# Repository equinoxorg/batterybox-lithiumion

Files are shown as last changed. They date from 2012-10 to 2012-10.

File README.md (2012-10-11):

# 3.7V Lithium Ion Battery Box Prototype

Electrial Engineering Final Year Project Deliverable
Charith Amarasinghe <ca508@ic.ac.uk>

3.7V Li-Ion Battery Box Prototype

## Features

* 1SxP Lithium Ion Battery Configuration (~1A nominal charge current)
* Li-Ion Fuel Gauge
* 2x 5V/1A USB outputs with short-circuit and overcurrent protection
* Authenticated charge support via MicroUSB
* Charge support from DC input (compatible with small PV panels)
* Constant Current LED driver (1-2W dimmable)
* Additional UART support (via Molex PicoBlade connectors) for datalogging applications
* 2x User Control Buttons
* LED indicators for low battery, USB fault and charge status

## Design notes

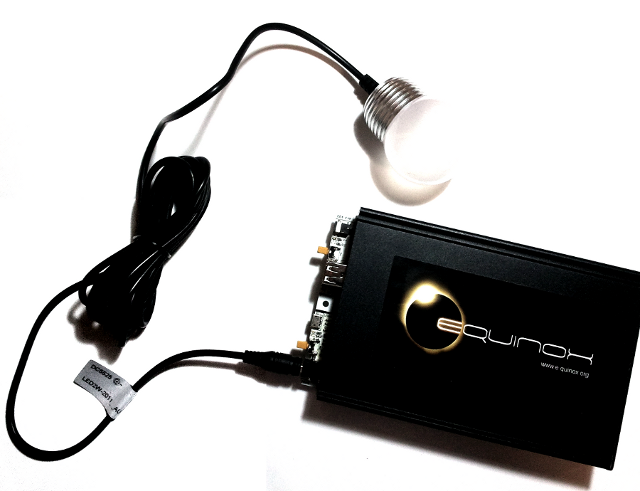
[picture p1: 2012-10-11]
media/proto.png

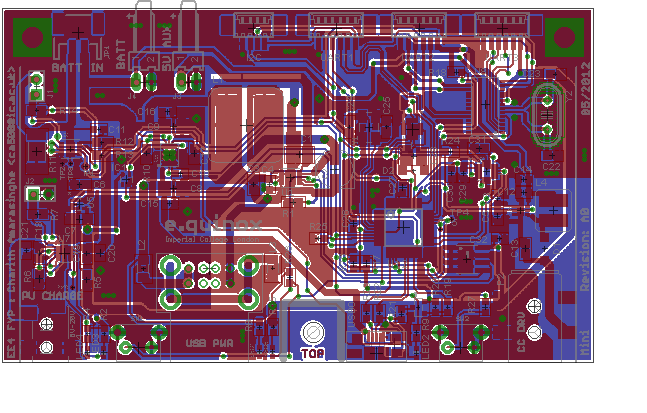
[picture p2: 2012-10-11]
media/pcb.png

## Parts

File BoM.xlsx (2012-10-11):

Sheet: Sheet1
Part | Value | Device | Package | Description | FARNELL | OC_FARNELL
!RESET! | TPSTP13SQ | TPSTP13SQ | TP13SQ | TEST PIN
1V8 | TPSTP13SQ | TPSTP13SQ | TP13SQ | TEST PIN
C1 | 22uF | C-EUC1210 | C1210 | CAPACITOR, European symbol | 1907362
C2 | 150uF | CPOL-EUD | PANASONIC_D | POLARIZED CAPACITOR, European symbol | 1850096
C3 | 10uF | C-EUC0805 | C0805 | CAPACITOR, European symbol | 1833812
C4 | 0.1uF | C-EUC0603 | C0603 | CAPACITOR, European symbol
C5 | 220nF | C-EUC0603 | C0603 | CAPACITOR, European symbol
C6 | 100nF | C-EUC0805 | C0805 | CAPACITOR, European symbol
C7 | 1uF | C-EUC1206 | C1206 | CAPACITOR, European symbol
C8 | 10uF | CPOL-EUB/3528-21R | B/3528-21R | POLARIZED CAPACITOR, European symbol | CA06845
C9 | 10uF | CPOL-EUB/3528-21R | B/3528-21R | POLARIZED CAPACITOR, European symbol | CA06845
C10 | 1n | C-EUC0603 | C0603 | CAPACITOR, European symbol
C11 | 10n | C-EUC0603 | C0603 | CAPACITOR, European symbol
C12 | 1uF | C-EUC0603 | C0603 | CAPACITOR, European symbol | 1828798
C13 | 1uF | C-EUC0805 | C0805 | CAPACITOR, European symbol | 1735541
C14 | 0.1uF | C-EUC0603 | C0603 | CAPACITOR, European symbol
C15 | 100n | C-EUC0603 | C0603 | CAPACITOR, European symbol
C16 | 100n | C-EUC0603 | C0603 | CAPACITOR, European symbol
C17 | 1uF | C-EUC0805 | C0805 | CAPACITOR, European symbol
C18 | 1uF | C-EUC0805 | C0805 | CAPACITOR, European symbol | 1735541
C19 | 1uF | C-EUC0805 | C0805 | CAPACITOR, European symbol | 1833845
C20 | 100n | C-EUC0603 | C0603 | CAPACITOR, European symbol
C21 | 100n | C-EUC0603 | C0603 | CAPACITOR, European symbol
C22 |  | C-EUC0805 | C0805 | CAPACITOR, European symbol
C23 |  | C-EUC0805 | C0805 | CAPACITOR, European symbol
C24 |  | C-EUC0805 | C0805 | CAPACITOR, European symbol
C25 |  | C-EUC0805 | C0805 | CAPACITOR, European symbol
C26 | 100n | C-EUC0603 | C0603 | CAPACITOR, European symbol
C27 | 100n | C-EUC0603 | C0603 | CAPACITOR, European symbol
C28 | 0.015F | C-EUC3225 | C3225 | CAPACITOR, European symbol
C29 | 0.1uF | C-EUC0603 | C0603 | CAPACITOR, European symbol
C30 | 0.1uF | C-EUC0603 | C0603 | CAPACITOR, European symbol
C31 | 4.7uF | C-EUC0805 | C0805 | CAPACITOR, European symbol
C32 | 0.1uF | C-EUC0603 | C0603 | CAPACITOR, European symbol
D1 | MBR0540T1 | MBR0520LT | SOD123 | SCHOTTKY BARRIER RECTIFIER | 9556923
D2 |  | DIODE-SOD123 | SOD123 | DIODE
GND | TPSTP13SQ | TPSTP13SQ | TP13SQ | TEST PIN
I2C | 53261-04 | 53261-04 | 53261-04 | CONNECTOR |  | 1125374
IC1 | 74LVC1G06DCK | 74LVC1G06DCK | SC70-5 | Single Inverter Buffer/Driver With Open-Drain Output
J1 | F-1X02-SIP-100-40 | F-1X02-SIP-100-40 | SIP-100-02-40 | FEMALE HEADER
J2 | F-1X02-SIP-100-40 | F-1X02-SIP-100-40 | SIP-100-02-40 | FEMALE HEADER
J3 | 22-05-7028-02 | 22-05-7028-02 | 7395-02 | CONNECTOR |  | 9731601
J4 | 22-05-7028-02 | 22-05-7028-02 | 7395-02 | CONNECTOR |  | 9731601
JP1 |  | M02-JST-2MM-SMT | JST-2-SMD | Header 2
L1 | 2.2uH | SDR1006-XXXKL | SDR1006 |  | 1828074
L2 | 30ohm | L-EUL3216C | L3216C | INDUCTOR, European symbol | FT01179
L3 | 30ohm | L-EUL3216C | L3216C | INDUCTOR, European symbol | FT01179
L4 | 22uH | VLCF5020-1 | VLCF-SERIES |  | 1670099
LED1 | USB_ON | LEDCHIP-LED0603 | CHIP-LED0603 | LED
LED2 | USB_CHG_GD | LEDCHIP-LED0603 | CHIP-LED0603 | LED
LED3 | CHG | LEDCHIP-LED0603 | CHIP-LED0603 | LED
LED4 | PG | LEDCHIP-LED0603 | CHIP-LED0603 | LED
LED5 | USB_FAULT | LEDCHIP-LED0603 | CHIP-LED0603 | LED
LED6 | USRLED | LEDCHIP-LED0603 | CHIP-LED0603 | LED
P1 | CLIFF_DCJACK1.3MM | CLIFF_DCJACK1.3MM | FC68145S
P2 | CLIFF_DCJACK2.1-2.5MM | CLIFF_DCJACK2.1-2.5MM | FC6814XS
Q1 | MMBT2907 | TRANSISTOR_PNPSOT23-REFLOW | SOT23-R | PNP Transistor
R1 | 28.7k | R-EU_R0805 | R0805 | RESISTOR, European symbol | 1160233
R2 | 100 | R-EU_R0603 | R0603 | RESISTOR, European symbol
R3 | 2.7 | R-EU_R0603 | R0603 | RESISTOR, European symbol | 1717778
R4 | 100 | R-EU_R0603 | R0603 | RESISTOR, European symbol
R5 | RDPM | R-EU_R0805 | R0805 | RESISTOR, European symbol
R6 | 800 | R-EU_R0805 | R0805 | RESISTOR, European symbol
R7 | RVTSB | R-EU_R0805 | R0805 | RESISTOR, European symbol
R8 | 1K | R-EU_R0603 | R0603 | RESISTOR, European symbol
R9 | 200 | R-EU_R0603 | R0603 | RESISTOR, European symbol
R10 | 80k | R-EU_R0805 | R0805 | RESISTOR, European symbol
R11 | 0.015 | R-EU_R2512 | R2512 | RESISTOR, European symbol | 1107396
R12 | 150 | R-EU_R0805 | R0805 | RESISTOR, European symbol
R13 | 1K | R-EU_R0805 | R0805 | RESISTOR, European symbol
R14 | 10K | R-EU_R0805 | R0805 | RESISTOR, European symbol
R15 | 100 | R-EU_R0603 | R0603 | RESISTOR, European symbol
R16 | 2.7k | R-EU_R0603 | R0603 | RESISTOR, European symbol
R17 | 2.7k | R-EU_R0603 | R0603 | RESISTOR, European symbol
R18 | 1.5k | R-EU_R0603 | R0603 | RESISTOR, European symbol
R19 | 2K | R-EU_R0603 | R0603 | RESISTOR, European symbol
R20 | 10K | R-EU_R0603 | R0603 | RESISTOR, European symbol
R21 | 1.5K | R-EU_R0603 | R0603 | RESISTOR, European symbol
R22 | 33 | R-EU_R0603 | R0603 | RESISTOR, European symbol
R23 | 33 | R-EU_R0603 | R0603 | RESISTOR, European symbol
R24 | 2.7k | R-EU_R0603 | R0603 | RESISTOR, European symbol
R25 | 10K | R-EU_R0603 | R0603 | RESISTOR, European symbol
R26 | 2.7k | R-EU_R0603 | R0603 | RESISTOR, European symbol
R27 | 2.7k | R-EU_R0603 | R0603 | RESISTOR, European symbol
R28 | 500 | R-EU_R0603 | R0603 | RESISTOR, European symbol
R29 | 2.7k | R-EU_R0603 | R0603 | RESISTOR, European symbol
SW1 | B3F-3152 | B3F-3152 | B3F-315X
SW2 | B3F-3152 | B3F-3152 | B3F-315X
SWCLK | TPSTP13SQ | TPSTP13SQ | TP13SQ | TEST PIN
SWDIO | TPSTP13SQ | TPSTP13SQ | TP13SQ | TEST PIN
TP1 | TPTP14R | TPTP14R | TP14R | Test pad
TP2 | TPTP07R | TPTP07R | TP07R | Test pad
TP3 | TPTP07R | TPTP07R | TP07R | Test pad
TP4 | TPTP07R | TPTP07R | TP07R | Test pad
TP5 | TPTP07R | TPTP07R | TP07R | Test pad
TP6 | TPTP07R | TPTP07R | TP07R | Test pad
U1 | TPS2500 | TPS2500DRCT | SON50P300X300X100-11N | INTEGRATED USB POWER SWITCH WITH BOOST CONVERTER |  | 1774589
U2 | DS2786G+ | DS2786G+ | DFN300X300X80-11N |  |  | -
U3 | ISL9203 | ISL9203 | INTERSIL_DFN_3X3 | The ISL9203R5220 is an integrated single-cell Li-ion or | 1361031
U4 | IP4220CZ6 | IP4220CZ6 | SOT95P275X110-6N | Dual Schmitt-Trigger Inverter |  | 1506629
U5 | NCP4588DSQ25T1G | NCP4588DSQ25T1G | SOT65P210X110-5N | Linear Voltage Regulator |  | 1885132
U6 | TPS61160ADRVT | TPS61160ADRVT | SON65P210X210X80-7N | White LED Driver With PWM Brightness Control in 2mm x 2mm QFN Package for up to 10 LEDs in Series |  | 1735594
U7 | BQ24210DQCT | BQ24210DQCT | SON50P200X300X80-11N | Single Cell Li-Ion Battery Solar Charger |  | 1903633
U8 | M41T62Q6F | M41T62Q6F | QFN50P300X300X100-17N | Serial real-time clocks with alarm |  | 1224441
U9 | MMA8453Q | MMA8453Q | QFN50P300X300X100-16N
U10 | SC16IS752 | SC16IS752 | TSSOP28
U11 | EEPROM-I2CSMD | EEPROM-I2CSMD | SO08 | I2C EEPROM chips, 24LC256 (and others)
U12 | LPC11U24FBD48/401 | LPC11U24FBD48/401 | LQFP48
UART1 | 53261-06 | 53261-06 | 53261-06 | CONNECTOR |  | 1125375
UART2 | 53261-06 | 53261-06 | 53261-06 | CONNECTOR |  | 1125375
UART3 | 53261-06 | 53261-06 | 53261-06 | CONNECTOR |  | 1125375
USB0 | TE1981584-1 | TE1981584-1 | TE-MICROUSB-AB
USB2 | MULTICOMP-MC32594 | MULTICOMP-MC32594 | MC32594
Y1 | TXC-7B | TXC-7B | TXC-7B
Y2 | 1.8432M | CRYSTALHC49UV | HC49U-V | Various standard crystals. Proven footprints. Spark Fun Electronics SKU : COM-00534
Y3 | 32.768kHz | CRYSTAL32-SMD | CRYSTAL-32KHZ-SMD | Various standard crystals. Proven footprints. Spark Fun Electronics SKU : COM-00534

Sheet: Parts List
MiniBox |  |  |  |  |  | Date: | 2012-06-01
 |  |  |  |  |  | Schematic: | mini.sch
Ref. | Group | Qty | Description | Cost | Vendor | Order Code | Notes | 100x Cost | Ordered | Order Qty
U1 | BOOST | 1 | TPS2500 USB Power Switch and Boost | £2.97 | Newark | 1774589 | Newark Part
U2 | FG | 1 | DS2786G+ LiIon Fuel Gauge | £2.15 | RS | 732-7579 |  | £1.71
U3 | CHRG1 | 1 | ISL9203 LiIon Charger | £0.70 | Onecall | 1361031 |  | £0.59
U4 | USB | 1 | IP4220CZ6 ESD Prot | £0.30 | Onecall | 1506629 |  | £0.26
U5 | VREG | 1 | NCP4588DSQ 2.5V Regulator Low Iq | £0.26 | Onecall | 1885132 |  | £0.22
U6 | CCDRV | 1 | TPS61162 CC LED Driver | £2.18 | Onecall | 1735594 |  | £1.15
U7 | CHRG2 | 1 | BQ24210 LiIon Charger with PV | £2.94 | Onecall | 1903633 |  | £2.06
U8 | RTCC | 1 | M41T62Q6F RTCC | £1.13 | Onecall | 1224441 |  | £0.92
U9 | AXM | 1 | MMA8453Q Accelerometer | £1.55 | Onecall | 1842359 | Replacement: MMA8451 | £0.88
U10 | EXTSER | 1 | SC16IS752 I2C UART |  | RS |  | DNP for FYP builds
U11 | EEPROM | 1 | 24LC256 EEPROM I2C | £0.58 | Onecall | 1579573 |  | £0.98
U12 | LOGIC | 1 | LPC11U24FBD48/401 Cortex M0 MCU | £2.24 | Onecall | 2069972 |  | £2.16
USB0 | IO | 1 | TE 1981584-1 MicroAB Connector | £0.54 | Onecall | 1521869 |  | £0.52
USB2 | IO | 1 | Multicomp MC32594 USB Plug RA Stacked | £0.51 | Onecall | 1696535 |  | £0.23
Y1 | LOGIC | 1 | TXC-7B SMT 12MHz Crystal Oscillator | £0.83 |  | 1841964 |  | £0.54 | Y | 2
Y2 | EXTSER | 1 | 1.8432MHz Crystal HC-49UV |  |  |  | DNP for FYP builds
Y3 | RTCC | 1 | 32.768kHz Watch Crystal | £0.08 |  | 1652573 |  | £0.06 | Y | 2
UART1 | LOGIC | 3 | Molex PicoBlade 53261-06 | £0.70 |  | 1125375 | Not Ordered | £0.63
UART2 | EXTSER |  | ^^ |  |  | ^ | DNP for FYP builds
UART3 | EXTSER |  | ^^ |  |  | ^ | DNP for FYP builds
SW1 | UX | 2 | Omron B3F-3152 RA Switch | £0.19 |  | 1960966 | Accompanying switch caps | £0.17 | Y | 4
SW2 |  |  | ^^ |  |  | ^
SWC1 | UX | 1 | Omron B3F key cap - Yellow | £0.15 |  | 176437 |  | £0.15 | Y | 5
SWC2 | UX | 1 | Omron B3F key cap - Black | £0.13 |  | 176439 |  | £0.12 | Y | 5
R11 | FG | 1 | 0.015 OHM Resistor 2512 | £0.43 |  | 1107396 | MOQ 5 | £0.45 | Y | 5
R12 | FG | 1 | 150ohm Resistor 0805 | £0.02 |  | 9332596 |  |  | Y | 50
R13 | FG | 1 | 1Kohm Resistor 0805 | £0.011 |  | 1469847 | MOQ 50 | £0.01 | Y | 50
R14 | FG | 1 | 10K Resistor 0805 | £0.01 |  | 1469856 | MOQ 50 | 0.011 | Y | 50
C11 | FG | 1 | 10nF Capacitor 0603 |  |  |  | From G.24-L Order
JP1 | FG | 1 | JST PH Series Side Insertion Header - 2w | £0.28 |  | 9492615 | MOQ 10. From G.24-L Order | £0.22
J1 | FG |  | 2.54mm Headers |  |  |  | From parts bin
D1 | CCDRV | 1 | MBRS0520LT Diode SOD123 | £0.32 |  | 9556923 | MBR0540 | £0.14 | Y | 3
C5 | CCDRV | 1 | 220nF Capacitor 0603 | £0.01 |  | 1759019 | MOQ 100 |  | Y | 100
C12 | CCDRV | 1 | 1uF Capacitor 0603 | £0.04 |  | 1828798 | MOQ 10 | 0.023 | Y | 10
C13 | CCDRV | 1 | 1uF Capacitor 0805 | £0.25 |  | 1735541 | MOQ10. 1828853 from LT3652. | £0.17
C14 | CCDRV | 1 | 100nF Capacitor 0603 |  |  |  | Parts Bin (Upto 100)
L4 | CCDRV | 1 | 22uH Inductor VLCF5020T | £0.52 |  | 1670099 |  | £0.52 | Y | 3
R3 | CCDRV | 1 | 2.7ohm Resistor 0603 |  |  |  | 9334262 from LT3652
Q1 | USB | 1 | MMBT2907 PNP Transistor SOT23 | £0.01 |  | 1459099 |  | £0.01 | Y | 3
R19 | USB | 1 | 2Kohm Resistor 0603 | £0.01 |  | 2059609 | MOQ 50 |  | Y | 50
R20 | USB | 1 | 10Kohm Resistor 0603 | £0.01 |  | 2008360 | MOQ 50 |  | Y | 50
R21 | USB | 1 | 1.5Kohm Resistor 0603 | £0.06 |  | 9331808 | MOQ 50 |  | Y | 50
IC1 | CHRG1 | 1 | 74LVC1G06DCK Inverter O/D | £0.44 |  | 1741231 |  | £0.32 | Y | 3
C8 | CHRG1 | 2 | 10uF Capacitor Tant Case B | 0.12 |  | CA06845 | From G.24-L Order
C9 | CHRG1 |  | ^^ |  |  | ^^ | From G.24-L Order
C10 | CHRG1 | 1 | 1nF Capacitor 0603 | £0.004 |  | 1759088 | MOQ 100 |  | Y | 100
C15 | CHRG1 | 2 | 100nF Capacitor 0603 |  |  |  | Parts Bin (Upto 100)
C16 | CHRG1 |  | ^^ |  |  | ^^
C17 | CHRG1 | 1 | 1uF Capacitor 0805 |  |  |  | 1828853 from LT3652
R9 | CHRG1 | 1 | 200ohm Resistor 0603 |  |  |  | 1627729 from G24-L
R10 | CHRG1 | 1 | 80Kohm Resistor 0805 | £0.27 |  | 1353309 | 80.6! |  | Y | 3
LED2 | CHRG1 | 1 | LED 0603 Green | £0.05 |  | 1226372 |  |  | Y | 5
C29 | AXM | 2 | 100nF Capacitor 0603 |  |  |  | Parts Bin (Upto 100)
C30 | AXM |  | ^^ |  |  | ^^
C31 | AXM | 1 | 4.7uF Capacitor 0805 | £0.05 |  | 1833810 |  |  | Y | 10
LED6 | LOGIC | 1 | LED 0603 Green |  |  |  | Ordered above
R28 | LOGIC | 1 | 1Kohm Resistor 0603 | £0.01 |  | 2008355 | Replace 500ohm. MOQ 50. |  | Y | 50
R26 | LOGIC | 1 | 2.7Kohm Resistor 0603 |  |  |  | Switch pull-ups
R27 | LOGIC | 1 | 2.7Kohm Resistor 0603 |  |  |  | 9334262 from LT3652
C6 | VREG | 1 | 100nF Capacitor 0805 |  |  |  | Solder 0603 0.1uF Cap
C7 | VREG | 1 | 1uF Capacitor 1206 | £0.02 |  | 9227873 | MOQ 10 |  | Y | 10
R22 | USB | 2 | 22ohm Resistor 0603 | £0.01 |  | 2008345 | MOQ 50 |  | Y | 50
R23 | USB |  | ^^
C32 | EEPROM | 1 | 0.1uF Capacitor 0603 |  |  |  | Parts Bin (Upto 100)
C26 | LOGIC | 2 | 0.1uF Capacitor 0603 |  |  |  | Parts Bin (Upto 100)
C27 |  |  | ^^ |  |  | ^^
R29 | LOGIC | 1 | 2.7Kohm Resistor 0603 | £0.004 |  | 612534 | MOQ 50 |  | Y | 50
R16 | LOGIC | 2 | 2.7Kohm Resistor 0603
R17 |  |  | ^^
R24 | LOGIC | 1 | 2.7Kohm Resistor 0603
 | BOOST
 | CHRG2
P2 |  |  | 2.1mm Jack DC |  |  | 1889309 |  |  | Y | 3
P1 |  |  | 1.3mm Jack DC |  |  | 1889307 |  |  | Y | 3
 |  |  | Molex 39-00-0046 5556T2 terminals (Female) |  |  | 1756650 (http://onecall.farnell.com/molex/39-00-0046/terminal-socket-4-2mm-awg22-28/dp/1756650) |  |  | Y | 100
 |  |  | Molex Recpt. 0.5mm 3.00mm Height 70W |  |  | 1567716 |  |  | Y | 1
 |  |  | 0603 RED LED |  |  | 2079955 (http://onecall.farnell.com/kingbright/kpg-1608surkc-t/led-smd-0603-0-25mm-thin-red/dp/2079955) |  |  | Y | 5
R6 | CHRG2 | 3 | 510ohm Resistor (800mA Charge Current) | £0.08 |  | 1653016 (http://onecall.farnell.com/vishay-draloric/crcw0805510rfkea/thick-film-chip-resistor/dp/1653016) | MOQ1
R6 | CHRG2 | 3 | 806ohm Resistor (500mA Charge Current) | £0.05 |  | 1575771 (http://onecall.farnell.com/multicomp/mctc0525b8060t5e/resistor-806r-0805-0-1-25ppm-0/dp/1575771) | MOQ5
R5 | CHRG2 | 2 | DPM Resistor for 5.5V (13.3K) | £0.33 |  | 1353215 (http://onecall.farnell.com/welwyn/pcf0805r-13k3bt1/resistor-0805-13k3/dp/1353215) | MOQ1
C18,C20 | CHRG2 | 2 | 1uF 0805 Capacitor 0.169 | £0.17 |  | 1833845 (http://onecall.farnell.com/avx/08053c105k4z2a/capacitor-0805-x7r-25v-1uf/dp/1833845) | MOQ5
R15 | BOOST | 1 | 100ohm Resistor (0603)
L2 | BOOST | 5 | Ferrite Bead 30ohms @ 100Mhz (1206) | £0.04 |  | FT01179
L3 | BOOST
C1 | BOOST | 5 | 22uF Ceramic 1210 | £0.48 |  | 1907362 | MOQ5
C2 | BOOST | 1 | 150uF Panasonic Case D | £0.26 |  | 1850096
R1 | BOOST | 1 | 28.7K Resistor | £0.33 |  | 1160233 | E
C3 | BOOST | 1 | 10uF Ceramic 0805 | £0.08 |  | 1833812 | MOQ10
L1 | BOOST | 1 | 2.2uH SDR1006 Inductor | £0.69 |  | 1828074
 |  |  | 3x INA199A2 | £1.96 |  | 1815789 (http://onecall.farnell.com/texas-instruments/ina199a2rswt/ic-current-shunt-monitor-10uqfn/dp/1815789)

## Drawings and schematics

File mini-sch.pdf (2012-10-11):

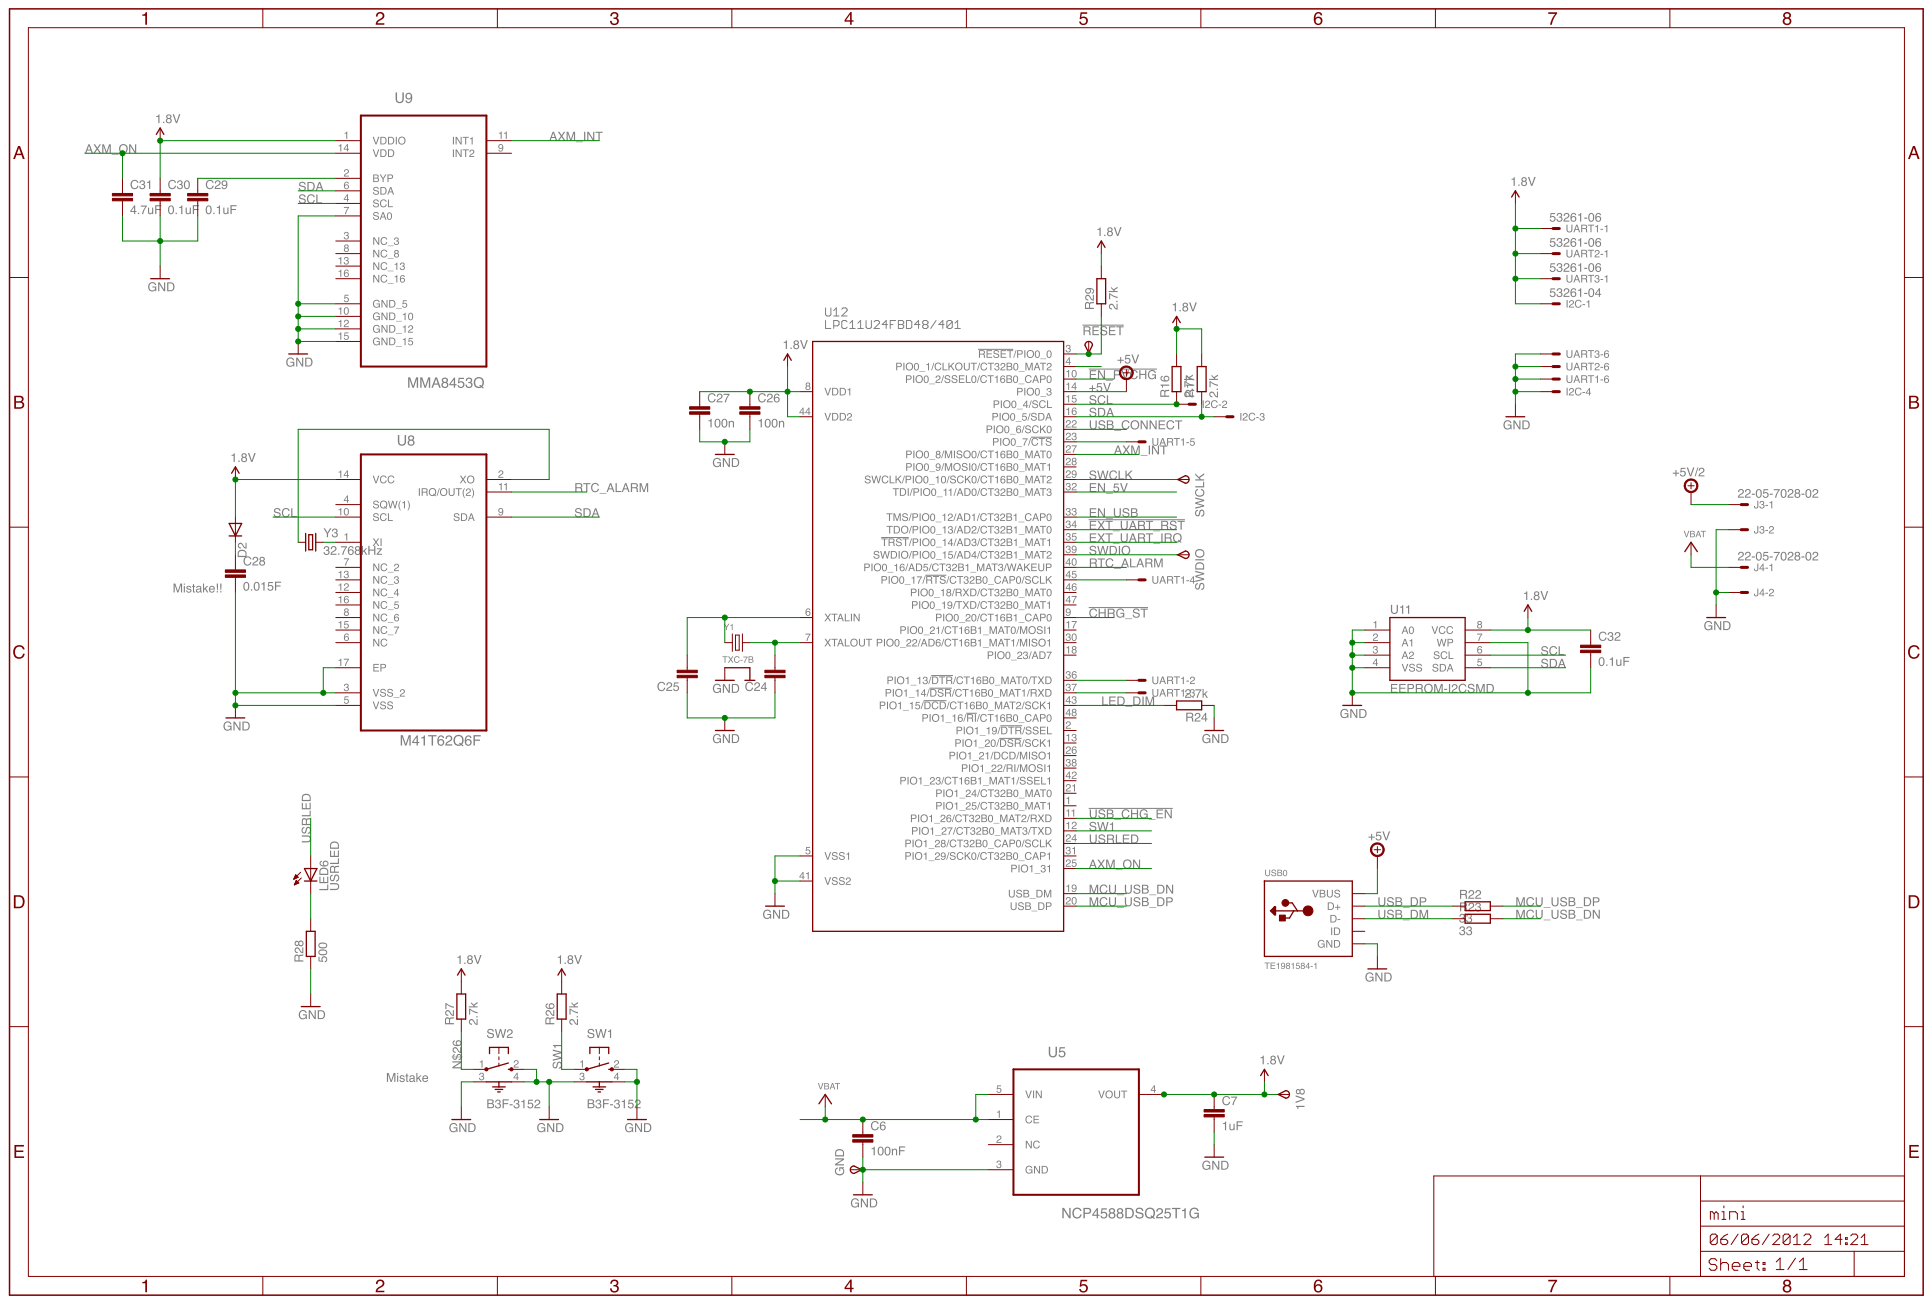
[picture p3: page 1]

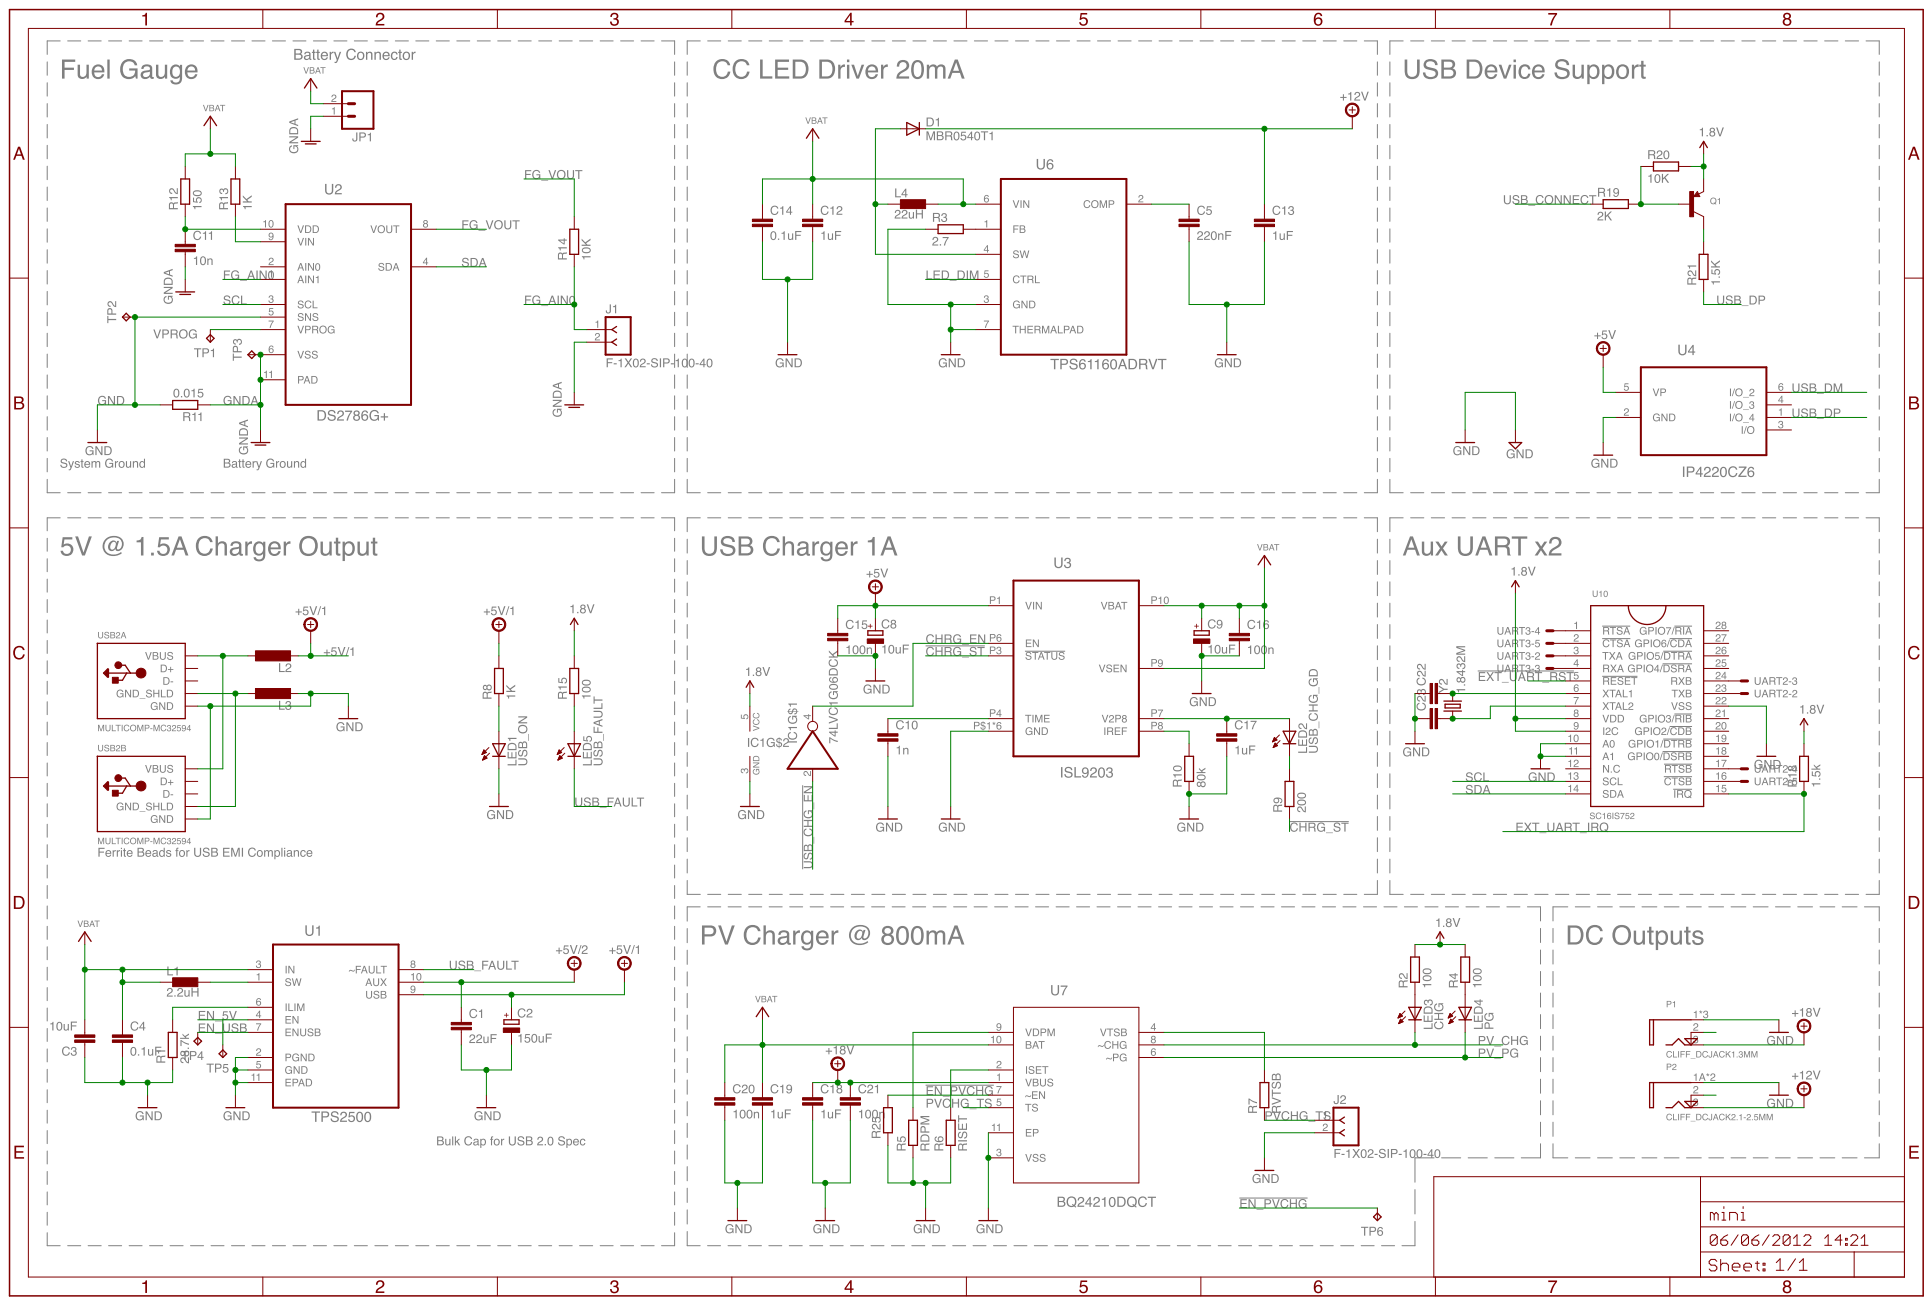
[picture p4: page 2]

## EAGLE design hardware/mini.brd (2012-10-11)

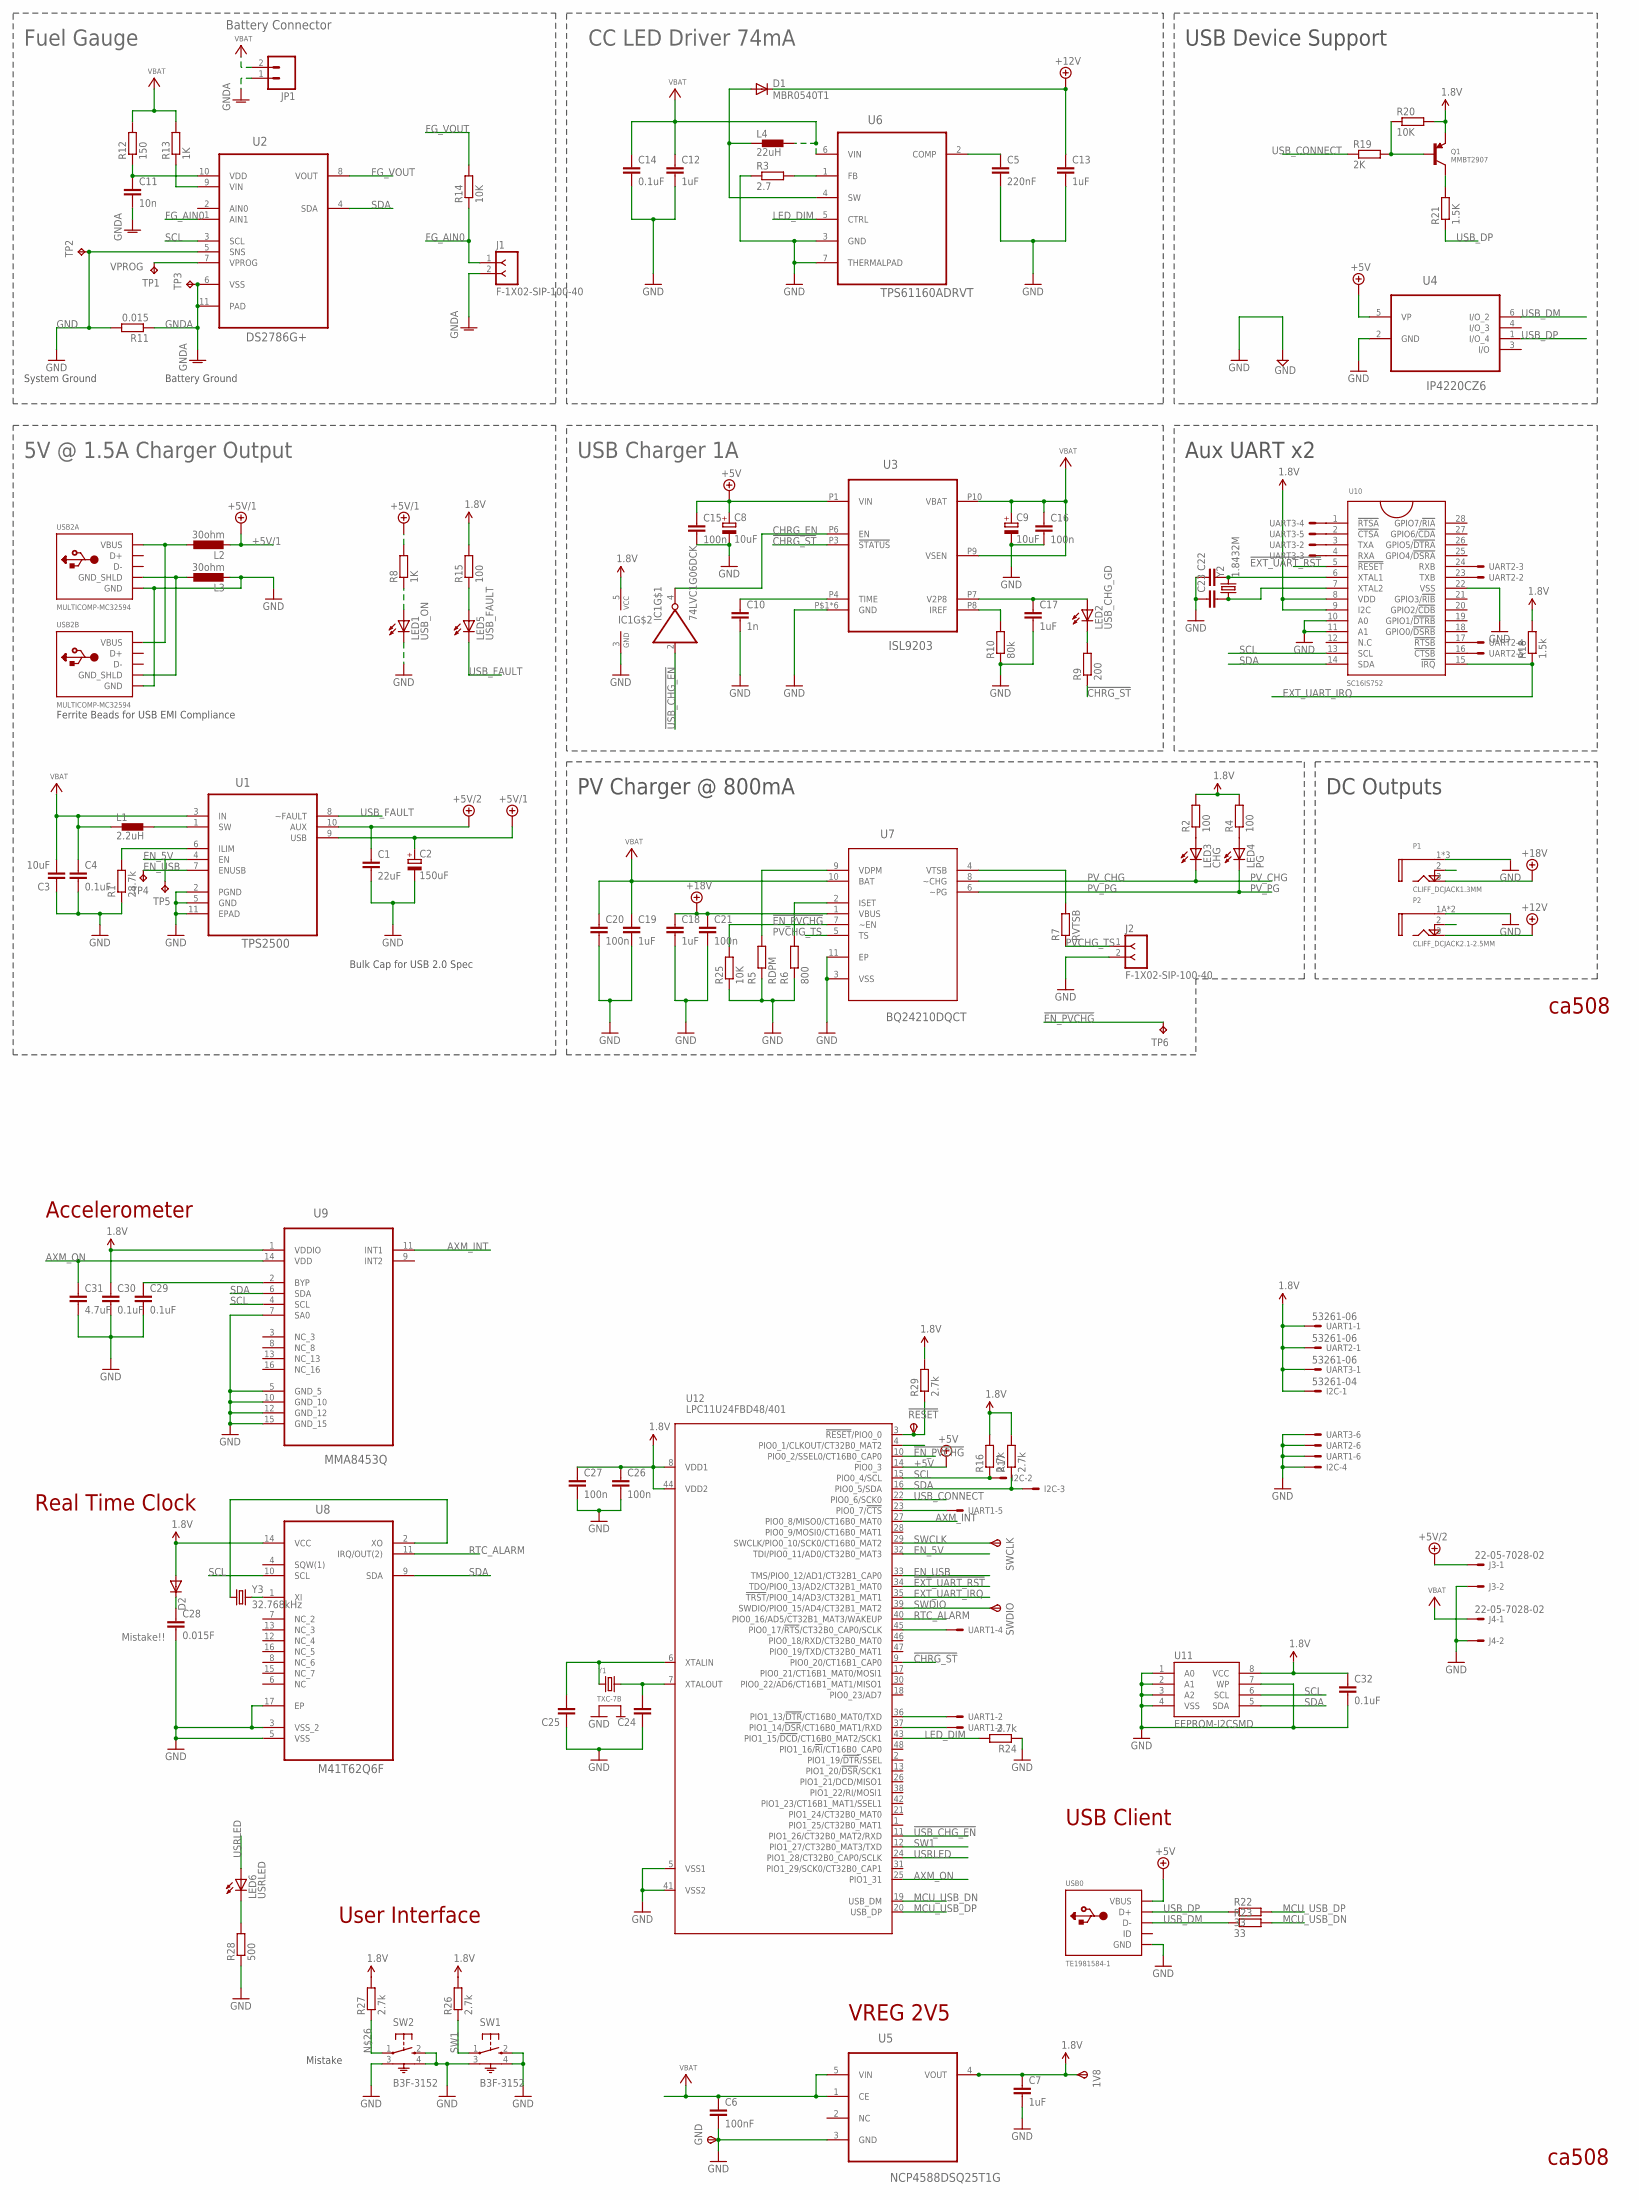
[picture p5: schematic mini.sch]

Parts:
1V8: TPSTP13SQ; TP13SQ
!RESET!: TPSTP13SQ; TP13SQ
C1: 22uF; C1210; FARNELL 1907362
C2: 150uF; PANASONIC_D; FARNELL 1850096
C3: 10uF; C0805; FARNELL 1833812
C4, C14, C29, C30, C32: 0.1uF; C0603
C5: 220nF; C0603
C6: 100nF; C0805
C7: 1uF; C1206
C8, C9: 10uF; B/3528-21R; FARNELL CA06845
C10: 1n; C0603
C11: 10n; C0603
C12: 1uF; C0603; FARNELL 1828798
C13, C18: 1uF; C0805; FARNELL 1735541
C15, C16, C20, C21, C26, C27: 100n; C0603
C17: 1uF; C0805
C19: 1uF; C0805; FARNELL 1833845
C22, C23, C24, C25: C-EUC0805; C0805
C28: 0.015F; C3225
C31: 4.7uF; C0805
D1: MBR0540T1; SOD123; FARNELL 9556923
D2: DIODE-SOD123; SOD123
GND: TPSTP13SQ; TP13SQ
I2C: 53261-04
IC1: 74LVC1G06DCK; SC70-5
J1, J2: F-1X02-SIP-100-40; SIP-100-02-40
J3, J4: 22-05-7028-02; 7395-02
JP1: M02-JST-2MM-SMT; JST-2-SMD
L1: 2.2uH; SDR1006; FARNELL 1828074
L2, L3: 30ohm; L3216C; FARNELL FT01179
L4: 22uH; VLCF-SERIES; FARNELL 1670099
LED1: USB_ON; CHIP-LED0603
LED2: USB_CHG_GD; CHIP-LED0603
LED3: CHG; CHIP-LED0603
LED4: PG; CHIP-LED0603
LED5: USB_FAULT; CHIP-LED0603
LED6: USRLED; CHIP-LED0603
P1: CLIFF_DCJACK1.3MM; FC68145S
P2: CLIFF_DCJACK2.1-2.5MM; FC6814XS
Q1: MMBT2907; SOT23-R
R1: 28.7k; R0805; FARNELL 1160233
R2, R4, R15: 100; R0603
R3: 2.7; R0603; FARNELL 1717778
R5: RDPM; R0805
R6: 800; R0805
R7: RVTSB; R0805
R8: 1K; R0603
R9: 200; R0603
R10: 80k; R0805
R11: 0.015; R2512; FARNELL 1107396
R12: 150; R0805
R13: 1K; R0805
R14: 10K; R0805
R16, R17, R24, R26, R27, R29: 2.7k; R0603
R18: 1.5k; R0603
R19: 2K; R0603
R20, R25: 10K; R0603
R21: 1.5K; R0603
R22, R23: 33; R0603
R28: 500; R0603
SW1, SW2: B3F-3152; B3F-315X
SWCLK: TPSTP13SQ; TP13SQ
SWDIO: TPSTP13SQ; TP13SQ
TP1: TPTP14R; TP14R
TP2, TP3, TP4, TP5, TP6: TPTP07R; TP07R
U1: TPS2500; SON50P300X300X100-11N
U2: DS2786G+; DFN300X300X80-11N
U3: ISL9203; INTERSIL_DFN_3X3
U4: IP4220CZ6; SOT95P275X110-6N
U5: NCP4588DSQ25T1G; SOT65P210X110-5N
U6: TPS61160ADRVT; SON65P210X210X80-7N
U7: BQ24210DQCT; SON50P200X300X80-11N
U8: M41T62Q6F; QFN50P300X300X100-17N
U9: MMA8453Q; QFN50P300X300X100-16N
U10: SC16IS752; TSSOP28
U11: EEPROM-I2CSMD; SO08
U12: LPC11U24FBD48/401; LQFP48
UART1, UART2, UART3: 53261-06
USB0: TE1981584-1; TE-MICROUSB-AB
USB2: MULTICOMP-MC32594; MC32594
Y1: TXC-7B
Y2: 1.8432M; HC49U-V
Y3: 32.768kHz; CRYSTAL-32KHZ-SMD

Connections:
1.8V: 1V8.TP, C7.1, C26.1, C27.1, C30.1, C32.1, D2.A, I2C.1, IC1.5 (VCC), Q1.2 (E), R2.2, R4.2, R15.2, R16.2, R17.2, R18.2, R20.2, R26.2, R27.2, R29.2, U5.4 (VOUT), U8.14 (VCC), U9.1 (VDDIO), U10.8 (VDD), U10.9 (I2C), U11.8 (VCC), U12.8 (VDD1), U12.44 (VDD2), UART1.1, UART2.1, UART3.1
!CHRG_ST!: R9.1, U3.P3 (!STATUS!), U12.9 (PIO0_20/CT16B1_CAP0)
!EN_PVCHG!: R25.2, TP6.TP, U7.7 (~EN), U12.10 (PIO0_2/SSEL0/CT16B0_CAP0)
!EXT_UART_RST!: U10.5 (!RESET!), U12.34 (TDO/PIO0_13/AD2/CT32B1_MAT0)
!USB_CHG_EN!: IC1.2 (I), U12.11 (PIO1_26/CT32B0_MAT2/RXD)
+5V: C8.+, C15.1, U3.P1 (VIN), U4.5 (VP), U12.14 (PIO0_3), USB0.P1 (VBUS)
+5V/1: C2.+, L2.2, R8.2, U1.9 (USB)
+5V/2: C1.1, J3.1, U1.10 (AUX)
+12V: C13.1, D1.C, P2.3 (TIP)
+18V: C18.1, C21.1, P1.3 (TIP), U7.1 (VBUS)
AXM_INT: U9.11 (INT1), U12.27 (PIO0_8/MISO0/CT16B0_MAT0)
AXM_ON: C31.1, U9.14 (VDD), U12.25 (PIO1_31)
CHRG_EN: IC1.4 (O), U3.P6 (EN)
EN_5V: TP5.TP, U1.4 (EN), U12.32 (TDI/PIO0_11/AD0/CT32B0_MAT3)
EN_USB: TP4.TP, U1.7 (ENUSB), U12.33 (TMS/PIO0_12/AD1/CT32B1_CAP0)
EXT_UART_IRQ: R18.1, U10.15 (!IRQ!), U12.35 (!TRST!/PIO0_14/AD3/CT32B1_MAT1)
FG_AIN0: J1.1, R14.1, U2.1 (AIN1)
FG_VOUT: R14.2, U2.8 (VOUT)
GND: C1.2, C2.-, C3.1, C4.2, C5.2, C6.2, C7.2, C8.-, C9.-, C10.2, C12.2, C13.2, C14.2, C15.2, C16.2, C17.2, C18.2, C19.2, C20.2, C21.2, C22.1, C23.1, C24.1, C25.1, C26.2, C27.2, C28.2, C29.2, C30.2, C31.2, C32.2, GND.TP, I2C.4, IC1.3 (GND), J2.2, J3.2, J4.2, L3.2, LED1.C, P1.1 (SLEEVE), P1.4A (SLEEVE), P1.4B (SLEEVE), P2.1A (SLEEVE), P2.1B (SLEEVE), R1.1, R3.1, R5.1, R6.1, R10.1, R11.2, R24.1, R25.1, R28.1, SW1.2 (3), SW1.3 (2), SW1.4, SW2.2 (3), SW2.3 (2), SW2.4, TP2.TP, U1.2 (PGND), U1.5 (GND), U1.11 (EPAD), U2.5 (SNS), U3.P5 (GND), U3.P$1 (GND), U3.P$2 (GND), U3.P$3 (GND), U3.P$4 (GND), U3.PAD (GND), U4.2 (GND), U5.3 (GND), U6.3 (GND), U6.7 (THERMALPAD), U7.3 (VSS), U7.11 (EP), U8.3 (VSS_2), U8.5 (VSS), U8.17 (EP), U9.5 (GND_5), U9.7 (SA0), U9.10 (GND_10), U9.12 (GND_12), U9.15 (GND_15), U10.10 (A0), U10.11 (A1), U10.22 (VSS), U11.1 (A0), U11.2 (A1), U11.3 (A2), U11.4 (VSS), U11.7 (WP), U12.5 (VSS1), U12.41 (VSS2), UART1.6, UART2.6, UART3.6, USB0.P5 (GND), USB2.USB1-4 (GND), USB2.USB2-4 (GND), Y1.2 (4), Y1.4
GNDA: C11.2, J1.2, JP1.1 (2), R11.1, TP3.TP, U2.6 (VSS), U2.11 (PAD)
LED_DIM: R24.2, U6.5 (CTRL), U12.43 (PIO1_15/!DCD!/CT16B0_MAT2/SCK1)
MCU_USB_DN: R23.2, U12.19 (USB_DM)
MCU_USB_DP: R22.2, U12.20 (USB_DP)
unnamed: L1.P$2 (2), U1.1 (SW)
unnamed: C11.1, R12.1, U2.10 (VDD)
unnamed: R10.2, U3.P8 (IREF)
unnamed: L2.1, USB2.USB1-1 (VBUS), USB2.USB2-1 (VBUS)
unnamed: C10.1, U3.P4 (TIME)
unnamed: L3.1, USB2.P$1 (GND_SHLD), USB2.P$2 (GND_SHLD), USB2.P$3 (GND_SHLD), USB2.P$4 (GND_SHLD)
unnamed: LED1.A, R8.1
unnamed: R13.1, U2.9 (VIN)
unnamed: LED2.C, R9.2
unnamed: R1.2, U1.6 (ILIM)
unnamed: D1.A, L4.1, U6.4 (SW)
unnamed: C17.1, LED2.A, U3.P7 (V2P8)
unnamed: C5.1, U6.2 (COMP)
unnamed: R3.2, U6.1 (FB)
unnamed: R7.2, U7.4 (VTSB)
unnamed: C28.1, D2.C
unnamed: R5.2, U7.9 (VDPM)
unnamed: R6.2, U7.2 (ISET)
unnamed: LED5.A, R15.1
unnamed: LED4.A, R4.1
unnamed: LED3.A, R2.1
unnamed: Q1.1 (B), R19.2, R20.1
unnamed: C22.2, U10.6 (XTAL1), Y2.2
unnamed: R27.1, SW2.1
unnamed: C24.2, U12.7 (XTALOUT), Y1.3 (2)
unnamed: C25.2, U12.6 (XTALIN), Y1.1
unnamed: LED6.C, R28.2
unnamed: U10.3 (TXA), UART3.2
unnamed: C23.2, U10.7 (XTAL2), Y2.1
unnamed: U10.4 (RXA), UART3.3
unnamed: U10.23 (TXB), UART2.2
unnamed: U10.24 (RXB), UART2.3
unnamed: U10.17 (!RTSB!), UART2.4
unnamed: U10.16 (!CTSB!), UART2.5
unnamed: U10.2 (!CTSA!), UART3.5
unnamed: U10.1 (!RTSA!), UART3.4
unnamed: U12.36 (PIO1_13/!DTR!/CT16B0_MAT0/TXD), UART1.2
unnamed: U12.37 (PIO1_14/!DSR!/CT16B0_MAT1/RXD), UART1.3
unnamed: U12.45 (PIO0_17/!RTS!/CT32B0_CAP0/SCLK), UART1.4
unnamed: U12.23 (PIO0_7/!CTS!), UART1.5
unnamed: U8.2 (XO), Y3.X1 (1)
unnamed: Q1.3 (C), R21.2
unnamed: U8.1 (XI), Y3.X2 (2)
unnamed: !RESET!.TP, R29.1, U12.3 (!RESET!/PIO0_0)
unnamed: C29.1, U9.2 (BYP)
PVCHG_TS: J2.1, R7.1, U7.5 (TS)
PV_CHG: LED3.C, U7.8 (~CHG)
PV_PG: LED4.C, U7.6 (~PG)
RTC_ALARM: U8.11 (IRQ/OUT(2)), U12.40 (PIO0_16/AD5/CT32B1_MAT3/WAKEUP)
SCL: I2C.2, R16.1, U2.3 (SCL), U8.10 (SCL), U9.4 (SCL), U10.13 (SCL), U11.6 (SCL), U12.15 (PIO0_4/SCL)
SDA: I2C.3, R17.1, U2.4 (SDA), U8.9 (SDA), U9.6 (SDA), U10.14 (SDA), U11.5 (SDA), U12.16 (PIO0_5/SDA)
SW1: R26.1, SW1.1, U12.12 (PIO1_27/CT32B0_MAT3/TXD)
SWCLK: SWCLK.TP, U12.29 (SWCLK/PIO0_10/SCK0/CT16B0_MAT2)
SWDIO: SWDIO.TP, U12.39 (SWDIO/PIO0_15/AD4/CT32B1_MAT2)
USB_CONNECT: R19.1, U12.22 (PIO0_6/SCK0)
USB_DM: R23.1, U4.6 (I/O_2), USB0.P2 (D-)
USB_DP: R21.1, R22.1, U4.1 (I/O_4), USB0.P3 (D+)
USB_FAULT: LED5.C, U1.8 (~FAULT)
USRLED: LED6.A, U12.24 (PIO1_28/CT32B0_CAP0/SCLK)
VBAT: C3.2, C4.1, C6.1, C9.+, C12.1, C14.1, C16.1, C19.1, C20.1, J4.1, JP1.2 (1), L1.P$1 (1), L4.2, R12.2, R13.2, U1.3 (IN), U3.P9 (VSEN), U3.P10 (VBAT), U5.1 (CE), U5.5 (VIN), U6.6 (VIN), U7.10 (BAT)
VPROG: TP1.TP, U2.7 (VPROG)

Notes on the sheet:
System Ground
Battery Ground
Ferrite Beads for USB EMI Compliance
Bulk Cap for USB 2.0 Spec
Battery Connector
Fuel Gauge
5V @ 1.5A Charger Output
USB Charger 1A
CC LED Driver 74mA
PV Charger @ 800mA
DC Outputs
Aux UART x2
USB Device Support
Mistake!!
Mistake
ca508
Real Time Clock
Accelerometer
User Interface
VREG 2V5
USB Client

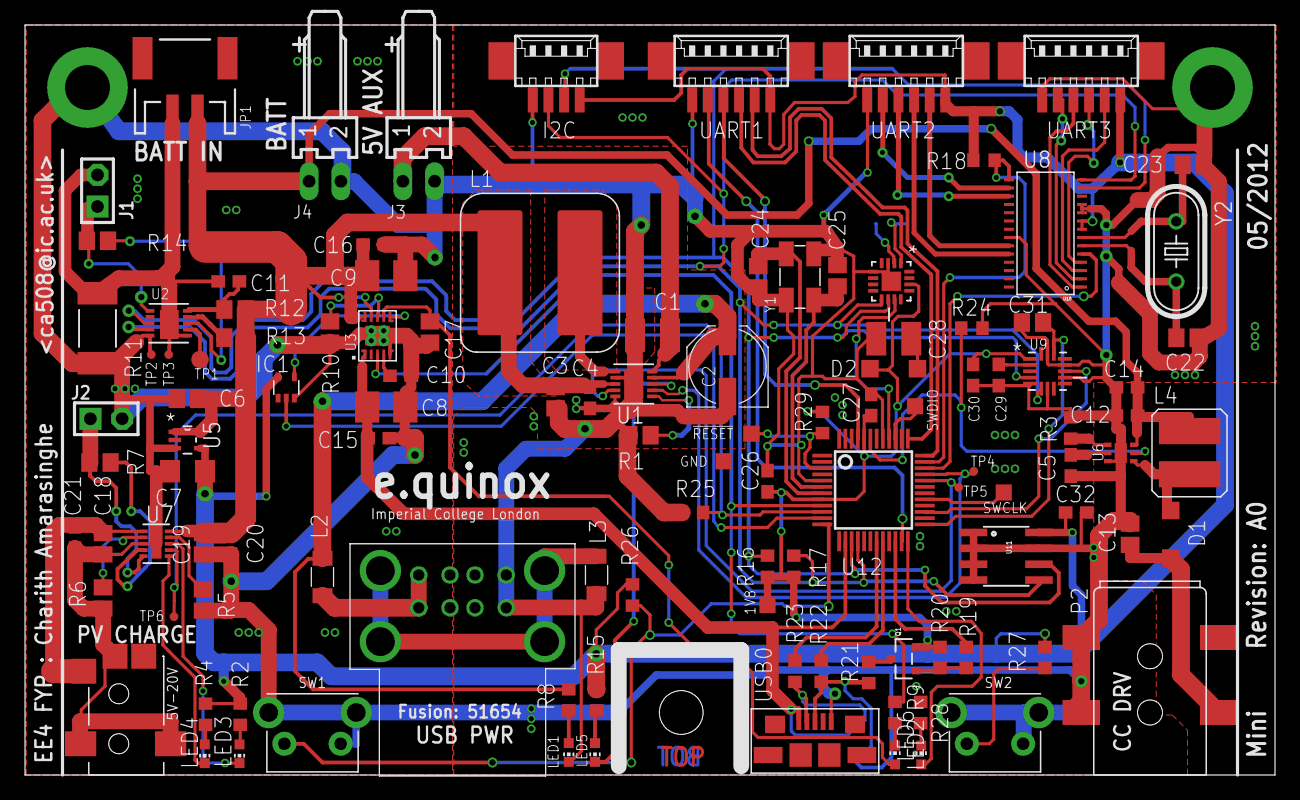
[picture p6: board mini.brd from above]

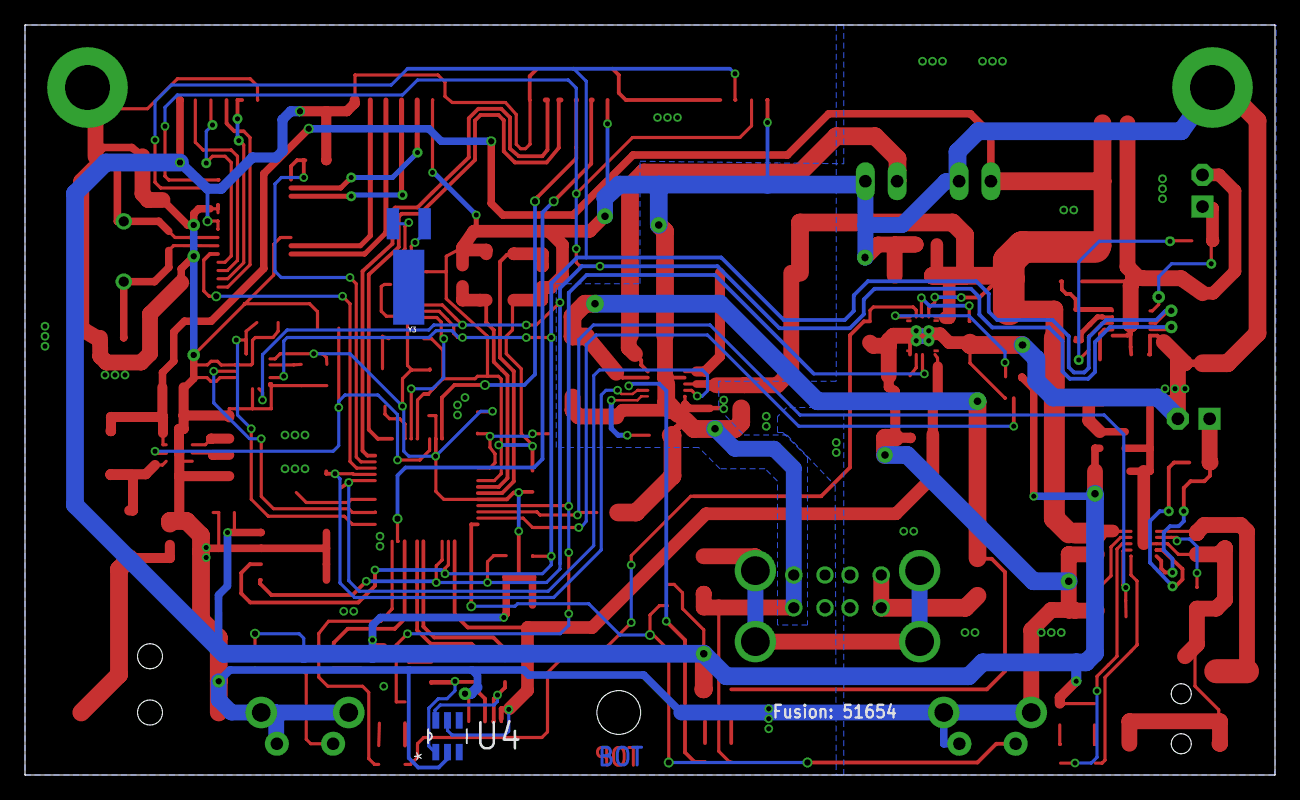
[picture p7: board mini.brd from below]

Board: 2 copper layers, 100.0 x 60.0 mm, 116 parts (2 on the bottom side), 84 nets.

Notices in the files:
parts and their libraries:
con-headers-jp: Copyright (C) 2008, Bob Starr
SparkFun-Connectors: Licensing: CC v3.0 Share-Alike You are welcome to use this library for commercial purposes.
